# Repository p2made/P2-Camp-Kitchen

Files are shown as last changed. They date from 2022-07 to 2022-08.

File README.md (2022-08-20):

# P2 Camp Kitchen

A tow bar mounted camping kitchen.

--

This work is licensed under the [GNU General Public License v2.0](LICENSE).

--

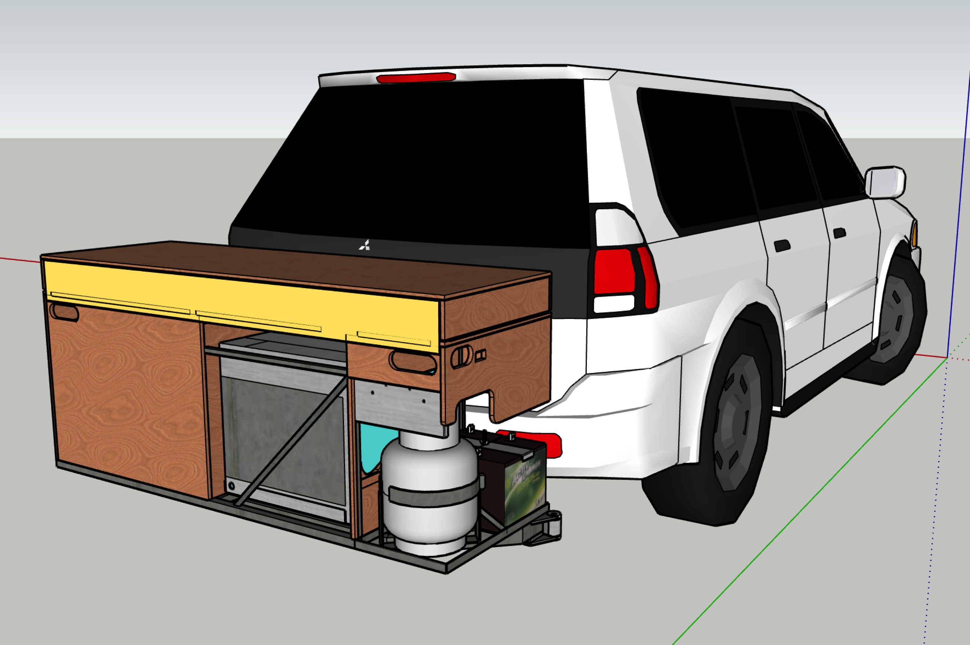
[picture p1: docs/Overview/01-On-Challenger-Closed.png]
01 On Challenger Closed

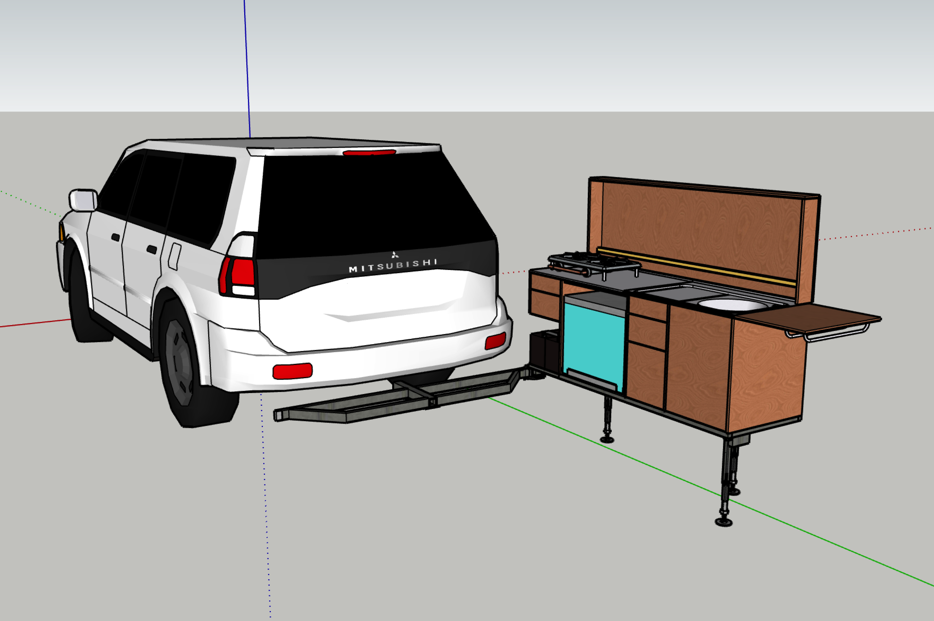
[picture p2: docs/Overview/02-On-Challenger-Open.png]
02 On Challenger Open


--
## Index

1. [Overview](#overview)
2. [Notes](#notes)
3. [Abbreviations](#abbreviations)

## Docs

1. [Detail](docs/Detail.md) ([PDF](docs/Detail.pdf))
2. [Frame](docs/Frame.md) ([PDF](docs/Frame.pdf))
3. [Plywood](docs/Plywood.md) ([PDF](docs/Plywood.pdf))
4. [Undercarriage](docs/Undercarriage.md) ([PDF](docs/Undercarriage.pdf))
5. [Components](docs/Components.md) ([PDF](docs/Components.pdf))
6. Electrical, Electronic, & Lighting
<!--6. [Electrical, Electronic, & Lighting](docs/Electrical.md) ([PDF](docs/Electrical.pdf))-->
7. [Sheet Metal](docs/Sheet-Metal.md) ([PDF](docs/Sheet-Metal.pdf))
8. Assemblies
<!--8. [Assemblies](docs/Assemblies.md) ([PDF](docs/Assemblies.pdf))-->

[PDF of this document](README.pdf).

##  Overview

03 Front
04 Back
05 Open Left
06 Open Right
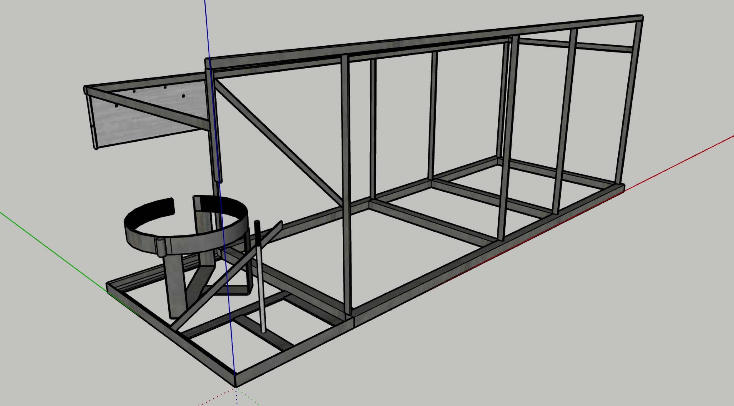
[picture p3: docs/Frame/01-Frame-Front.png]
01 Frame Front

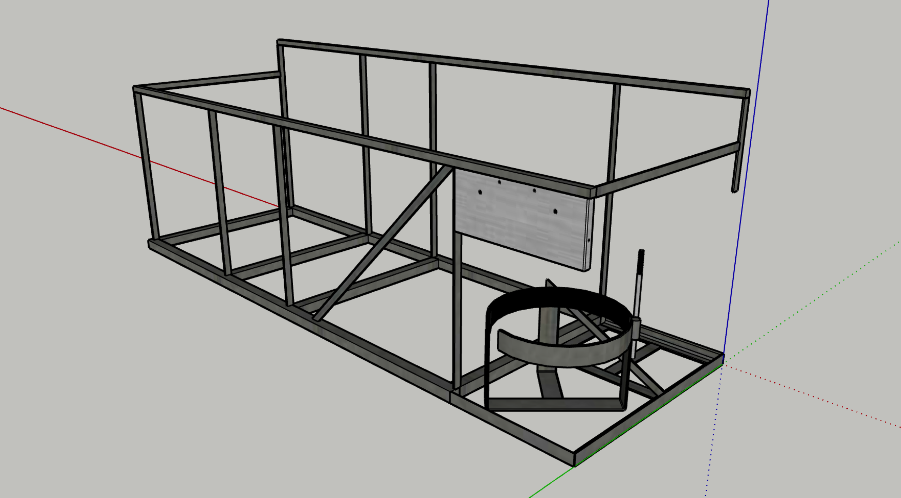
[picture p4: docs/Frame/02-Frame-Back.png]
02 Frame Back


##  *Notes*

“Front”, “Back”, “Left”, & “Right” are from the viewpoint of facing the 1600 mm side that is the kitchen front when deployed & to the front when stowed. That makes “left” & “right” opposite to car driver’s seat viewpoint.

##  Abbreviations

To be concise a number of arbitrary abbreviations are used throughout these docs. These are all defined here.

<table>
	<tr valign="top">
		<td width="33%">
			<dl>
				<dt>LH</dt><dd>Left Hand</dd>
				<dt>LF</dt><dd>Left hand Front</dd>
				<dt>LB</dt><dd>Left hand Back</dd>
			</dl>
		</td>
		<td width="33%">
			<dl>
				<dt>RH</dt><dd>Right Hand</dd>
				<dt>RF</dt><dd>Right hand Front</dd>
				<dt>RB</dt><dd>Right hand Back</dd>
			</dl>
		</td>
		<td width="33%">
			<dl>
				<dt>D</dt><dd>Drawer</dd>
				<dt>Dn</dt><dd>Drawer <i>n</i> = 1 to 5</dd>
			</dl>
		</td>
	</tr>
</table>

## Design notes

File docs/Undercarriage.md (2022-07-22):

# Undercarriage

1. [Overview](#01)
2. [Base](#02)
3. [Under Frame](#03)
4. [Energy Subframe](#04)
5. [Assembly](#05)

--

Made principally from…

* 25x50 mm RHS
* 50x50 mm RHS

**NOTE:** While researching I have seen "receiver" used for the towbar mounting socket on the vehicle, & "shank tube" for the part that plugs into the receiver. I use the same terms here.

##  Overview

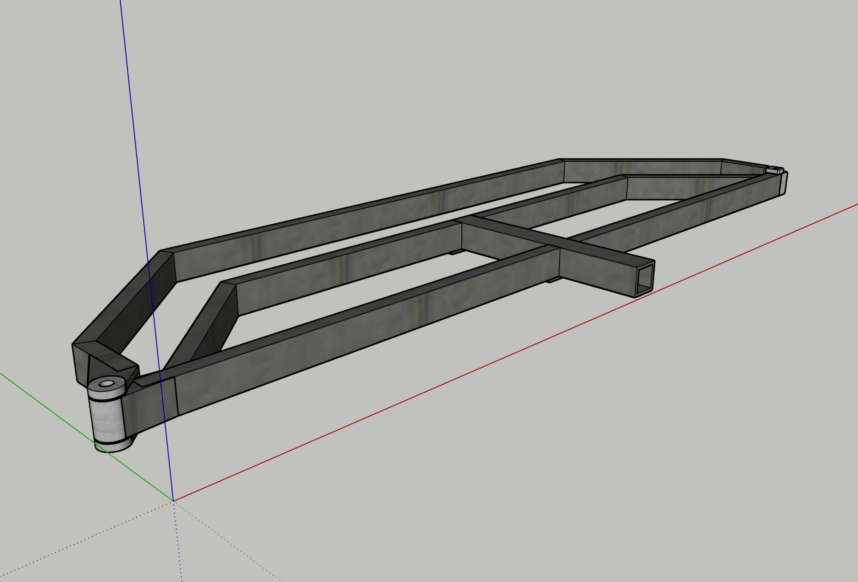
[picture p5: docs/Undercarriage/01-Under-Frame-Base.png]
01 Under Frame & Base


The design intention is for the bottom front rail of the box frame to be positioned directly above the front cross member of the base. 

##  Base

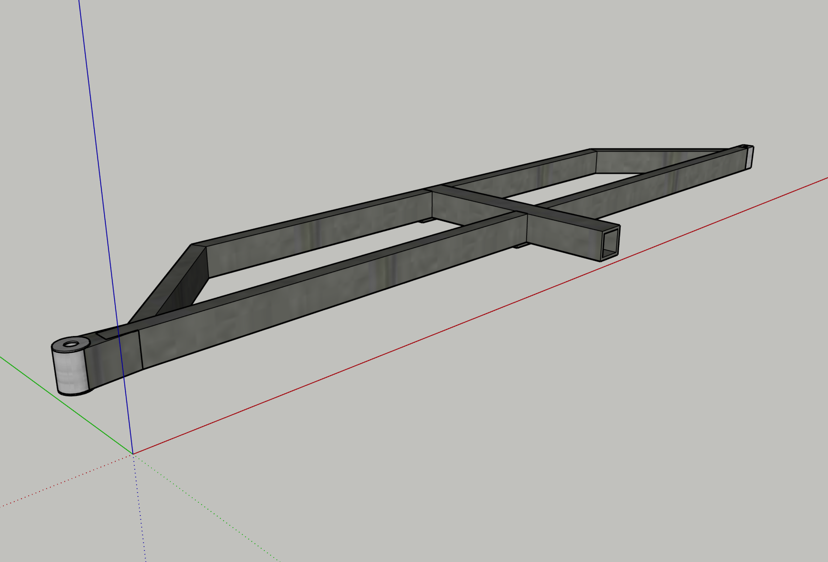
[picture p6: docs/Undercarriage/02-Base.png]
02 Base


The base mounts to the vehicle with the central tube serving as shank tube & going into the receiver on the vehicle.

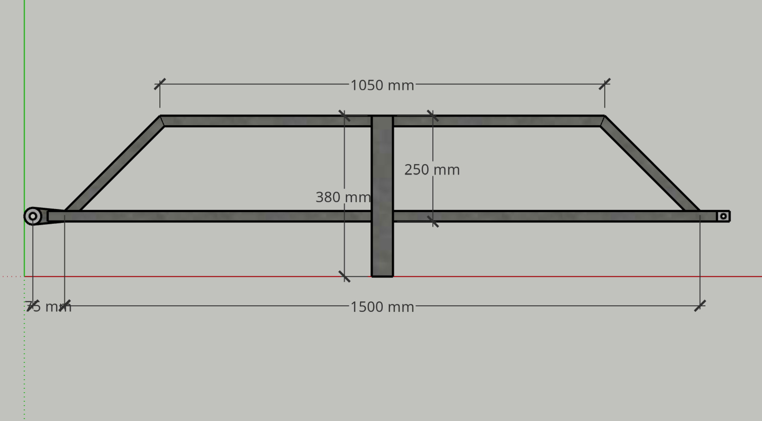
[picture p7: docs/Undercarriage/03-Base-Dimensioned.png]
03 Base Dimensioned


* The length of the shank tube is drawn to go the full 130 mm depth of the receiver on my vehicle. Making it a few mm shorter may be desirable.
* Hole to suit 5/8" hitch pin needs to be positioned to suit the receiver on my vehicle & is not drawn.
* Cross pieces to facilitate attachment of the step (see [Components](Components.md)) need to be add as the engineer sees fit.

The 1050 mm dimension above puts the angled members at 45°, however that only needs to be wide enough to fit the step underneath. The alternate drawing below makes that 600 mm (width of the step rounded up to 100 mm).

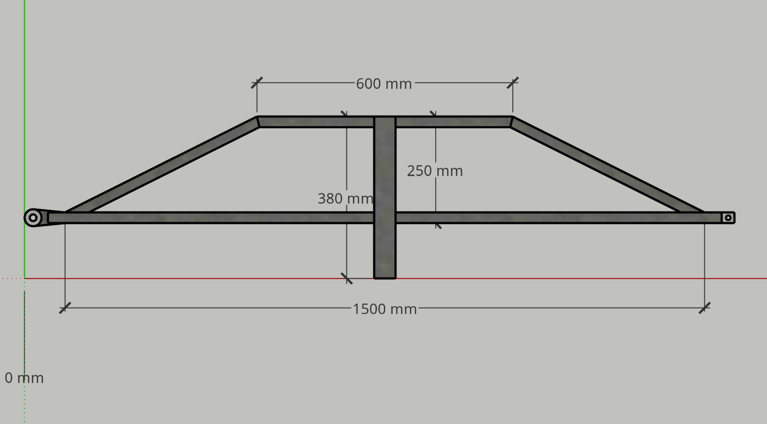
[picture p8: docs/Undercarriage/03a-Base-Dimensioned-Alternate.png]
03a Base Dimensioned Alternate


##  Under Frame

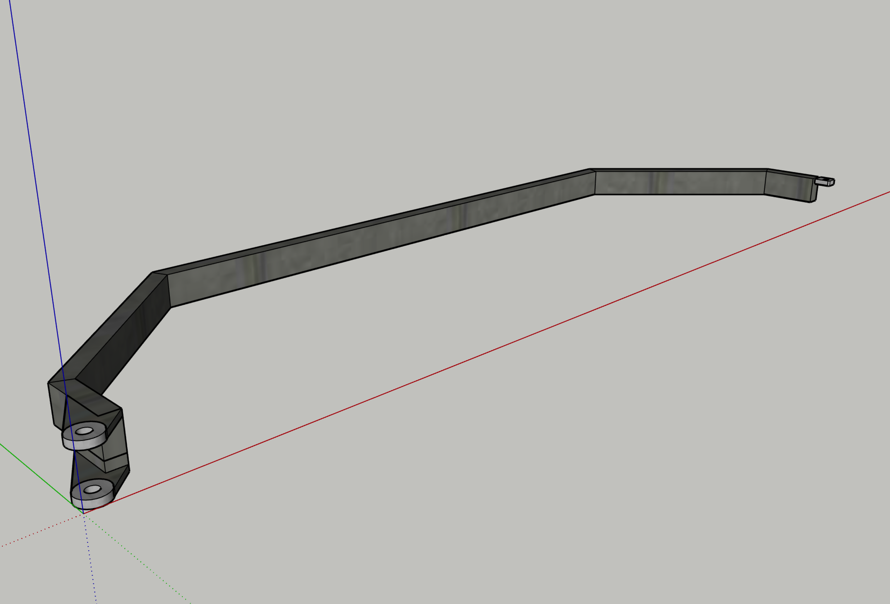
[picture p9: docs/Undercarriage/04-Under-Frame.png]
04 Under Frame


The Under Frame supports the kitchen box & provides the mounting points to the base.

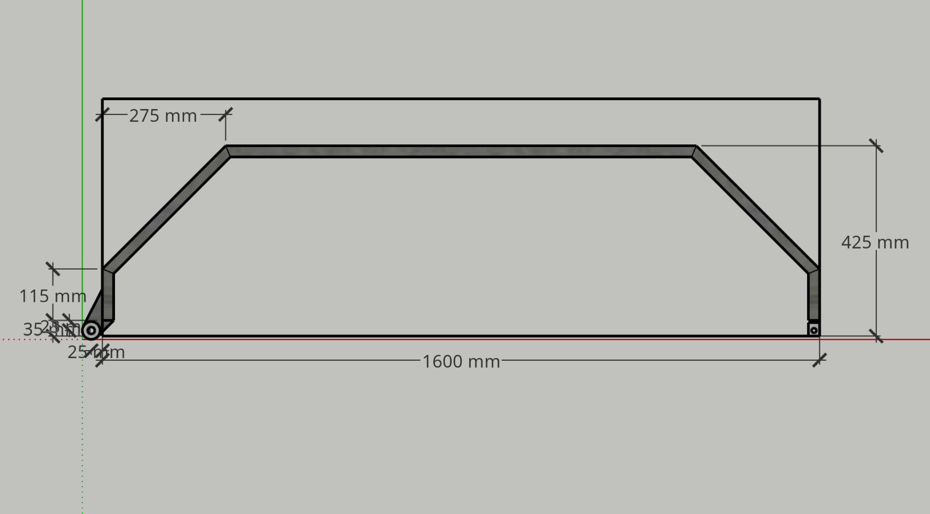
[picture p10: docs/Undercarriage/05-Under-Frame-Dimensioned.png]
05 Under Frame Dimensioned

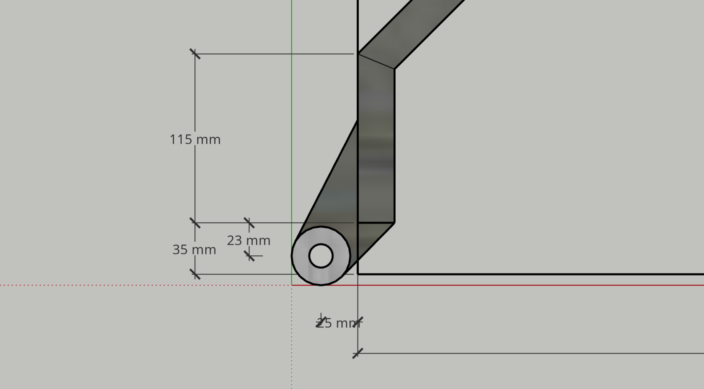
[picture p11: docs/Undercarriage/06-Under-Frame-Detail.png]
06 Under Frame Detail


<!--
## Pivot

[![07 Base Pivot](Undercarriage/07-Base-Pivot.png)](Undercarriage/07-Base-Pivot.pdf "07 Base Pivot")
[![08 Pivot Top](Undercarriage/08-Pivot-Top.png)](Undercarriage/08-Pivot-Top.pdf "08 Pivot Top")
[![09 Pivot Bottom](Undercarriage/09-Pivot-Bottom.png)](Undercarriage/09-Pivot-Bottom.pdf "09 Pivot Bottom")
[![10 Pivot Spacer](Undercarriage/10-Pivot-Spacer.png)](Undercarriage/10-Pivot-Spacer.pdf "10 Pivot Spacer")
-->

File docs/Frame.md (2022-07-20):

# Frame

1. [Overview](#01)
2. [Bottom Frame](#02)
3. [Front & Back Frames](#03)
4. [Energy Subframe](#04)
5. [Assembly](#05)

--

Made principally from…

* 25x25 mm RHS
* 15x15 mm RHS
* 16x3 mm flat steel
* 25x3 mm flat steel

##  Overview

01 Frame Front
02 Frame Back

##  Bottom Frame

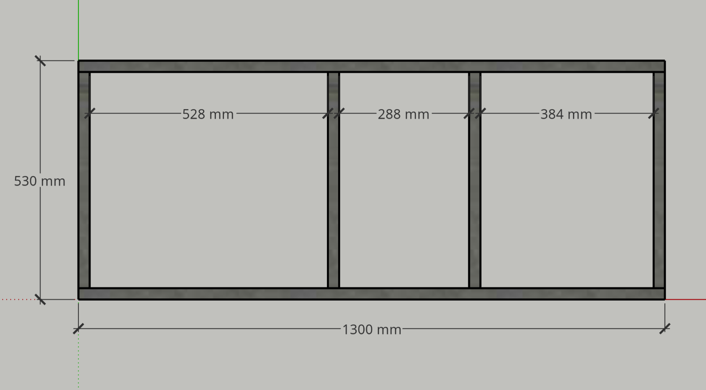
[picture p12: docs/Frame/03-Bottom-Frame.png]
03 Bottom Frame


* All 25x25 RHS.
* Bottom rails, 1300 mm long, spaced 480 mm apart.
* Cross members, 480 mm long, positioned as shown.

##  Front & Back Frames

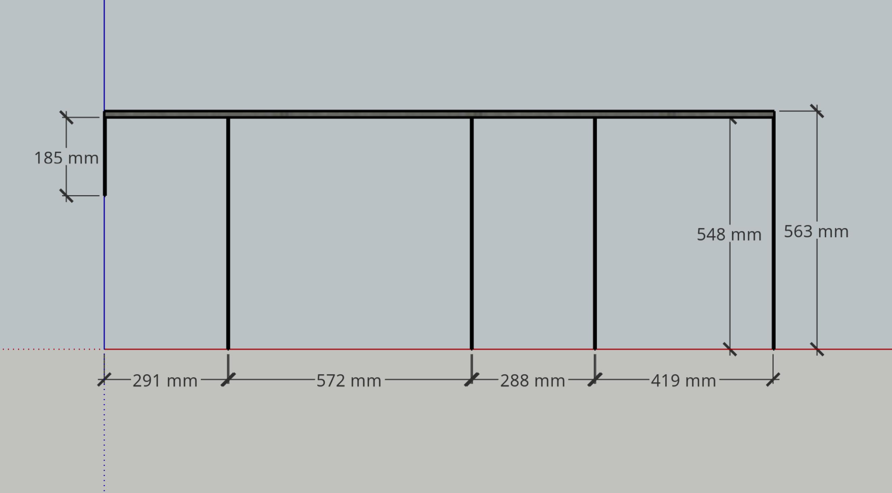
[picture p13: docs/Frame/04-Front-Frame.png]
04 Front Frame

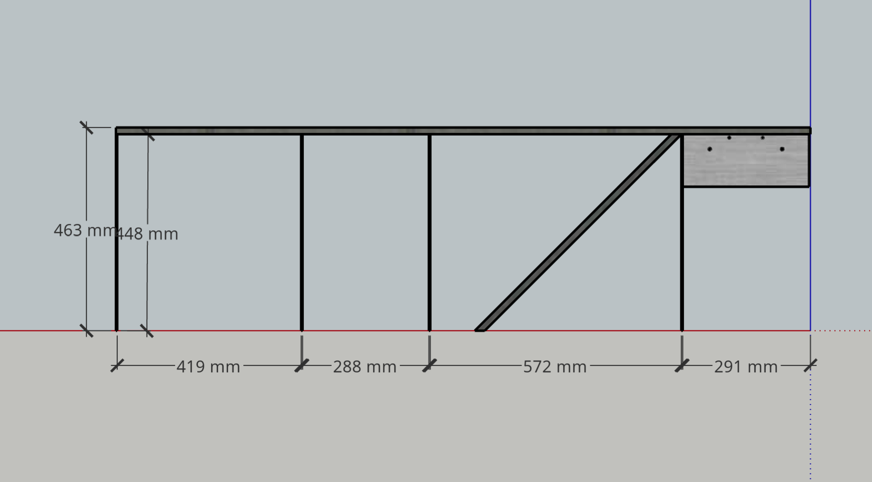
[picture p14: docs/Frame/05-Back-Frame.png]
05 Back Frame


The front & back frames are mirror images of each other with some differences.

* Top members of 15x15 RHS, 1582 long.
* Assembled flush to the outside face.
* Have vertical members of 16x3 flat attached as shown.

### Front Frame

* Vertical members are 548 mm for an overall height of 563 mm.
* Has an additional vertical member, 185 mm long, drawn attached *under* the LH end.
* That additional vertical member could be attached over the end by making appropriate adjustments to dimensions. It has been drawn attached under to minimise the number of items in a cutting list.

### Back Frame

* Vertical members are 448 mm for an overall height of 463 mm.
* Has a number plate mount attached as shown.
* Has a 45° diagonal brace as shown.

### Number Plate Mount

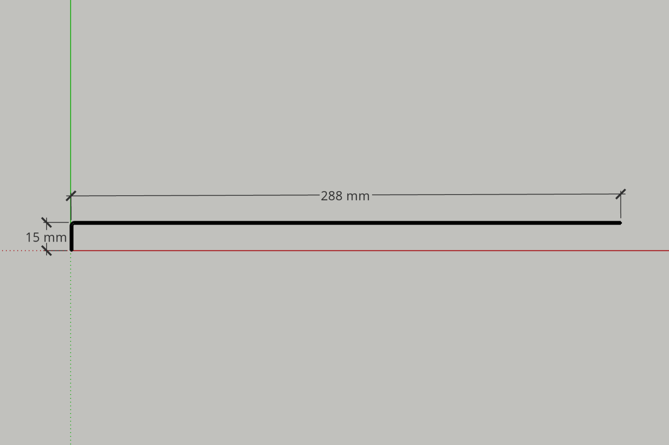
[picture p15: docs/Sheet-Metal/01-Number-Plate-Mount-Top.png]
01 Number Plate Mount Top

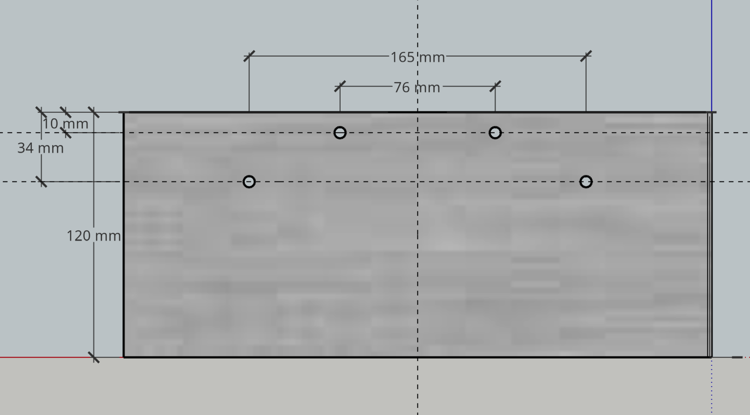
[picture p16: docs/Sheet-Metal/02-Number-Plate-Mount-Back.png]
02 Number Plate Mount Back


##  Energy Subframe

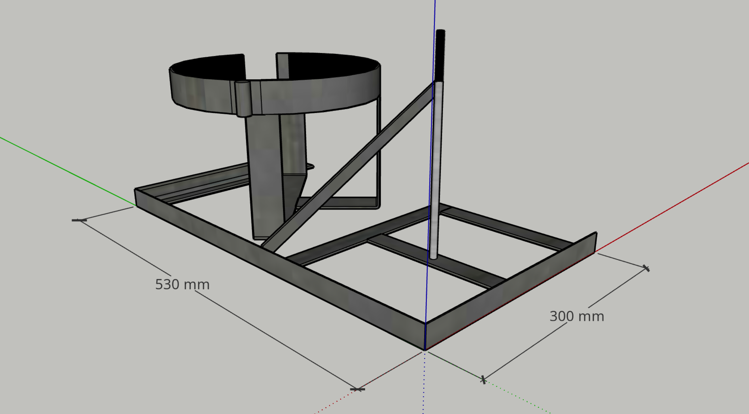
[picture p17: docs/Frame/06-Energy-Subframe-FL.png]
06 Energy Subframe FL

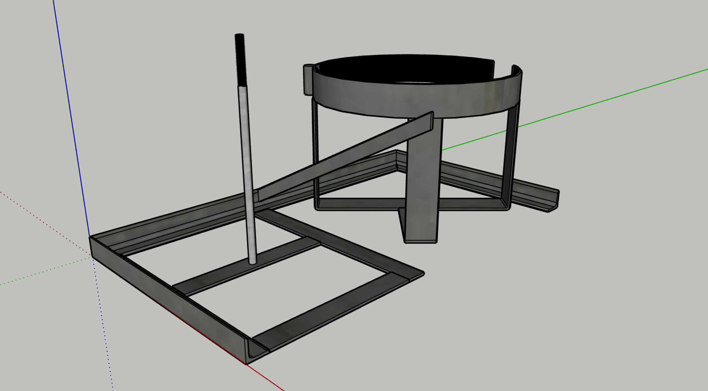
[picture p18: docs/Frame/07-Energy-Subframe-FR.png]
07 Energy Subframe FR


A subframe to support gas bottle & batteries.

Three sides of a rectangle 530 mm (one side) x 300 mm (both sides), made of 25x25 angle, as shown.

Plan views of the energy subframe with horizontal & vertical batteries…

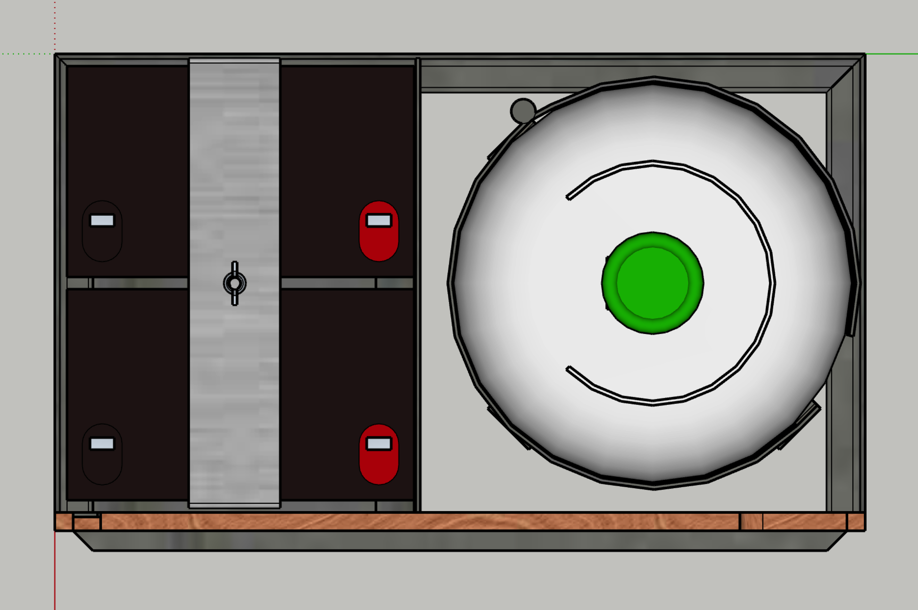
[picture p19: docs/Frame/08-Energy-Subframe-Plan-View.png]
08 Energy Subframe Plan View

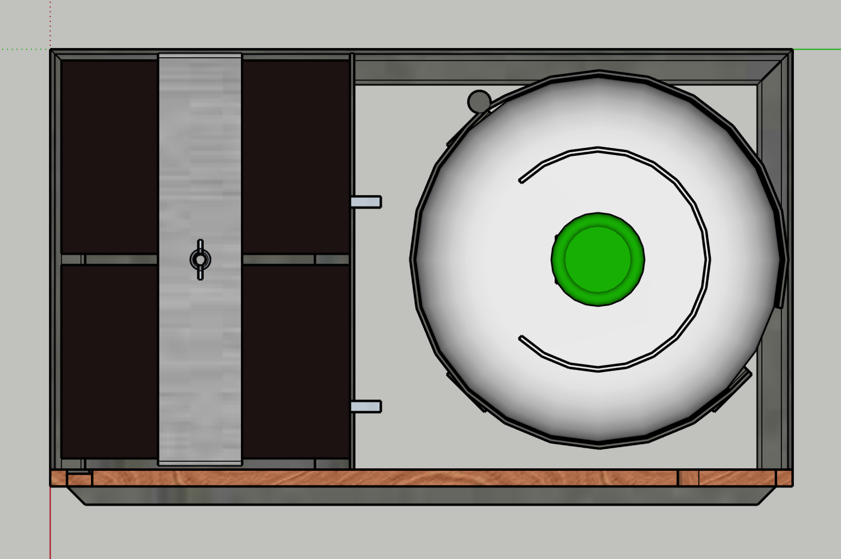
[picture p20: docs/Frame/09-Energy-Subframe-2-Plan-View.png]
09 Energy Subframe 2 Plan View


### Gas Bottle Holder

* An [eBay purchase](https://www.ebay.com.au/itm/254621457008).
* To be modified to sit at approximately 45 degrees within the  Energy Subframe to permit opening without interference.
* Drawings show it positioned 3 mm inside the imagary back face, & centred left to right.

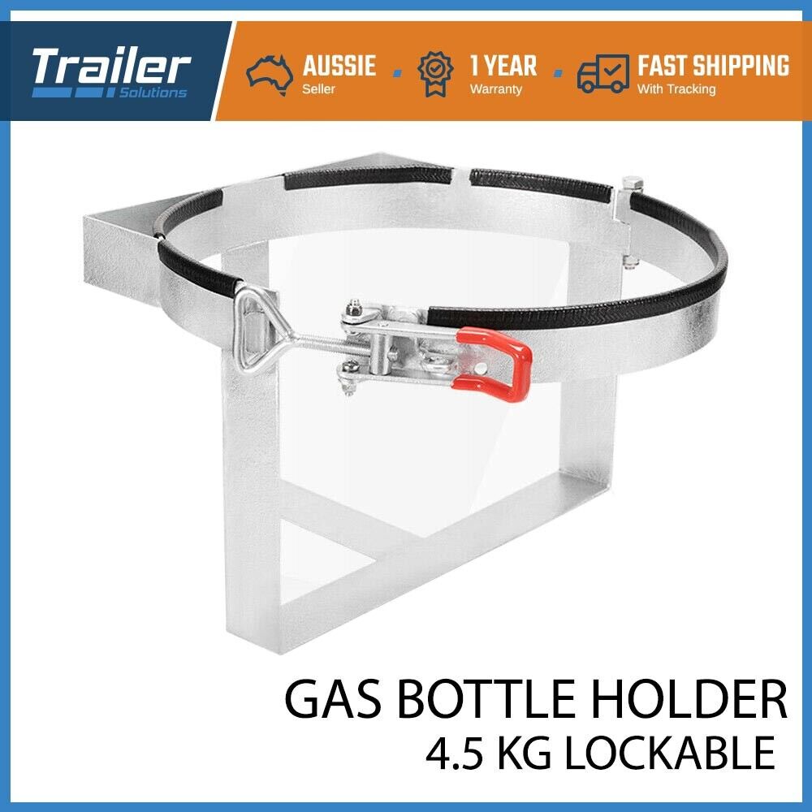
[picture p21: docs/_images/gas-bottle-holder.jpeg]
gas-bottle-holder


### Battery Holder

The battery holder as shown is for illustration only. It may be however the engineer chooses to achieve…

* Batteries positioned as close as practical to the inside face of the front angle.
* The first battery is positioned as close as practical to the inside face of the LH angle.
* The spaces between the batteries, & between the imaginary RH surface of the subframe, are approximately equal.
* The batteries are retained & kept in position by a simple, yet secure, means.

The diagonal brace shown is a possible way to maintain battery position in the back direction while adding support to the structure.

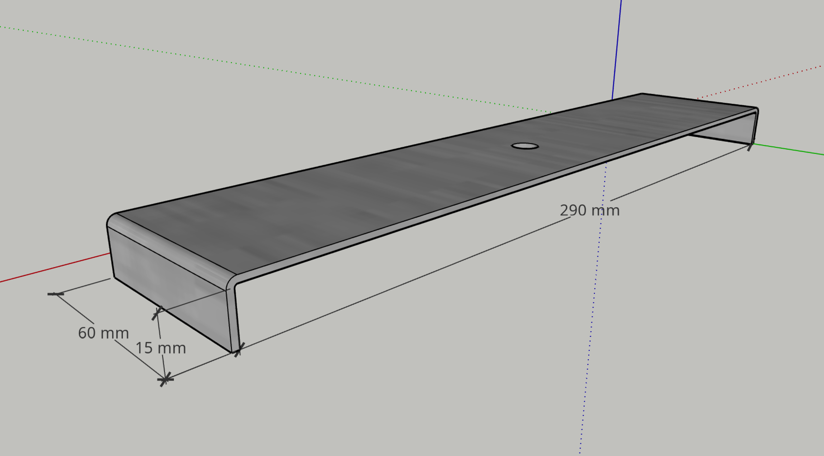
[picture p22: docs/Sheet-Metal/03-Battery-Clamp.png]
03 Battery Clamp


##  Assembly

The front & back frames are attached to the bottom frame…

* Flush to the LH end.
* 9 mm inboard of the RH end.
* 12 mm inboard of their respective faces.

There are 2 x cross members of 16 x 3 mm flat, & one cross member of 25 x 3 mm flat.

The 16 mm cross members are flush in the end planes of the top rails, running horizontally from the inside face of the back top rail to the adjacent front vertical.

The 25 mm cross member runs horizontally between the LH pair of verticals, at a height for attachment to the band of the gas bottle holder (with a spacer if necessary). The actual height must be advised for appliction to plywood cutting.

The energy rack is attached to the LH end of the bottom frame.

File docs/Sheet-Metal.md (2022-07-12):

# Sheet Metal

1. [Number Plate Mount](#01)
2. [Battery Clamp](#02)
3. [Fridge Tray Rails](#03)
4. [Stainless Steel Top](#04)
5. [Splash Back Cover](#05)

--

##  Number Plate Mount

* To be attached to the back frame.
* Drawn as 1 mm sheet metal.

01 Number Plate Mount Top
02 Number Plate Mount Back

##  Battery Clamp

* Drawn as 2 mm sheet metal.

03 Battery Clamp

##  Fridge Tray Rails

* Drawn as 2 mm sheet metal.

Side rails.

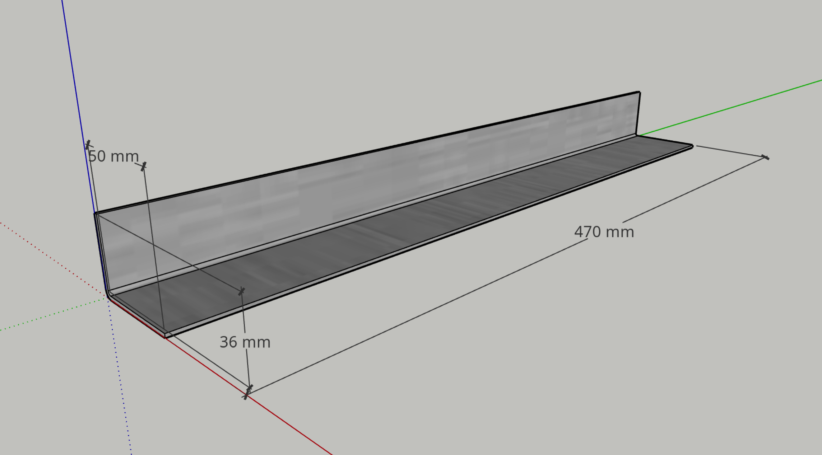
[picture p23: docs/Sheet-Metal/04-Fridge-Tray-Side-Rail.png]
04 Fridge Tray Side Rail


Front rail.

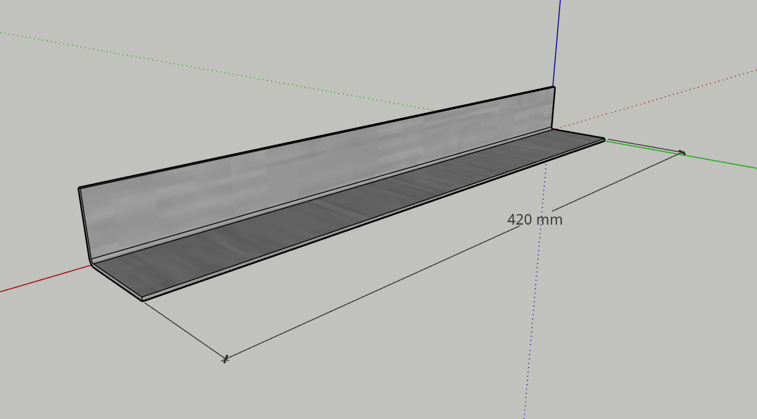
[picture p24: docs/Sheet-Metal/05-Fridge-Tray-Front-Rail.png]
05 Fridge Tray Front Rail


Back rail (same as front with cutout for access to pilot light hole).

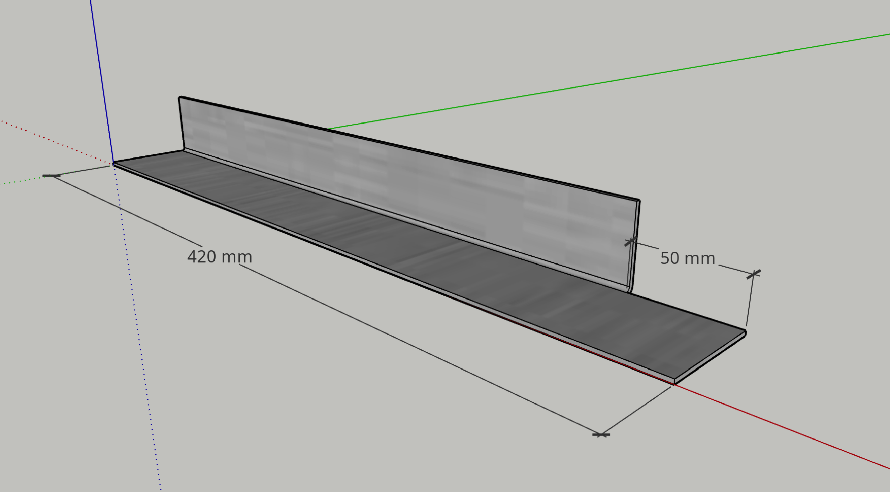
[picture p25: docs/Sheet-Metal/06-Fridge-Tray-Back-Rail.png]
06 Fridge Tray Back Rail


##  Stainless Steel Top

* To complement the sink in making a full stainless steel surface for the benchtop.
* Should have holes (not yet drawn) for stove attachment.
* Drawn as 1 mm, but should match the thickness of sink steel.

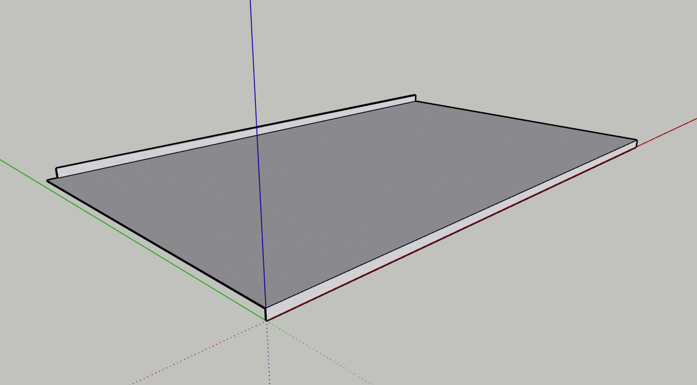
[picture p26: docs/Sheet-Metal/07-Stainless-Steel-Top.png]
07 Stainless Steel Top


##  Splash Back Cover

* A cover for the top & rear of splash back.
* Has a return section to enclose pipes & wiring above fridge.
* Dimensions shown are *inside* the folds.
* Drawn as 1 mm, but should be less.

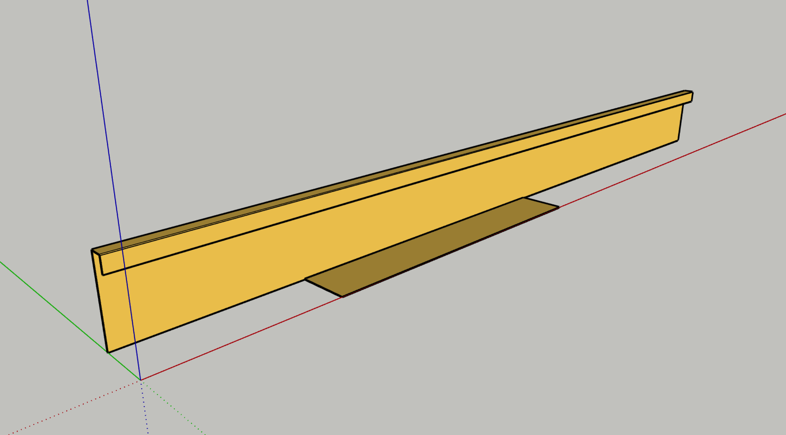
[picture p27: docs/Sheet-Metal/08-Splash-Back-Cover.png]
08 Splash Back Cover

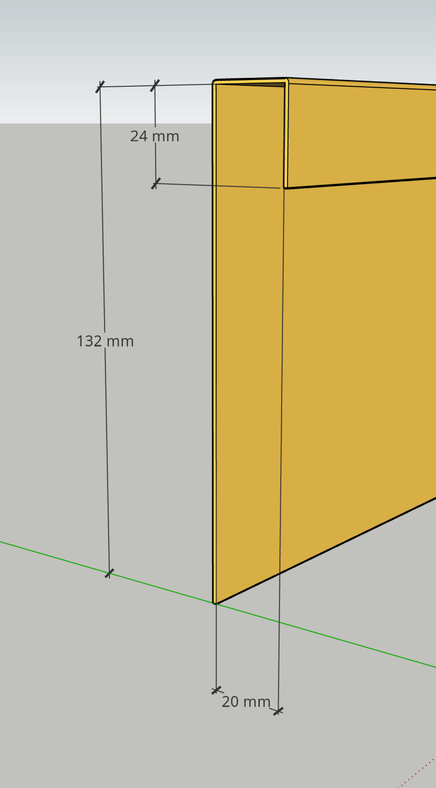
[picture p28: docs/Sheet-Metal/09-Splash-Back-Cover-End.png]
09 Splash Back Cover End


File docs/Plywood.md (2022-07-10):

# Plywood

1. [Cross Panels](#01)
2. [Back Panels](#02)
3. [Benchtop](#03)
4. [Drawers](#04)
5. [Cupboard](#05)
6. [Splash Back](#06)
7. [Lid](#07)
8. [End Shelf](#08)

--

Pieces cut from 12 mm marine ply.

Where there is no drawing, there is either...

* No additional detail, or
* Additional details haven't yet been drawn.

##  Cross Panels

* Five cross members, LH, RH, & 1 to 3 numbered LH to RH.
* Routing is 3mm deep & drawn with 2 mm with clearance.

### End Panel LH

* 530 x 250 mm.
* Hole for water hoses.
* Hole (drawn) or recess for clearance light.
* Cutout for gas bottle access.

01 End Panel LH

### End Panel RH

* 530 x 563 mm.
* Hole (drawn) or recess for clearance light.

02 End Panel RH

### Cross Panel 1

* 530 x 563 mm.
* Hole for gas hose movement.
* Cutouts for frame top rails.
* Cutout for pipe & wiring.
* Cutout for LH back panel.

03 Cross Panel 1

### Cross Panel 2

* 518 x 563 mm.
* Cutouts for frame top rails.
* Cutout for pipe & wiring.

04 Cross Panel 2

### Cross Panel 3

* Mirror of cross panel 2.

05 Cross Panel 3

##  Back Panels

Two back panels, both having holes for mounting taillights.

* Back Panel LH: 300 x 115 mm.
* Back Panel RH: 722 x 563 mm.

06 Back Panel LH
07 Back Panel RH

##  Benchtop

* 1600 x 530 mm.
* Hole for sink.
* Cutout for wiring to splash back.

08 Benchtop

##  Drawers

Provision for hardware not yet shown.

Five drawers with front panels…

* Drawer fronts 1 & 3, 284 x 96 mm, for a nominal depth of 100 mm.
* Drawer fronts 2 & 4, 284 x 146 mm, for a nominal depth of 150 mm.
* Drawer front 5, 284 x 305 mm, for a nominal depth of 309 mm (with 4 mm clearance below).

Drawers 1 & 2 are special purpose drawers…

* Drawer 1, 350 mm long with the bottom set high for an effective depth of 50 mm.
* Drawer 2, 250 mm long with a rail across the top back instead of a back panel, so that there is a large opening for wiring.

The rest of the drawers are entirely standard, & as long as possible. Some internal division in drawers 3 & 4 may be desirable.

##  Cupboard

Door 406 x 555 mm. Provision for hardware not yet shown.

Floor 384 x 480 mm. Requires an opening at LB corner for passage of sink waste hose (drawn as 70 mm radius quarter circle).

13 Cupboard Floor

Shelf 410 x 500 mm. Requires hole under centre of sink bowl for passage of sink waste hose (drawn as 70 diameter but smaller would be preferable).

14 Cupboard Shelf

##  Splash Back

* 1570 x 100 mm.
* Holes (not yet drwan) near centre for switchgear.

##  Lid

Provision for hardware not yet shown.

Four sides of a 1600 x 530 x 112 mm box.
Pieces are…

* 1600 x 530 mm for top.
* 1600 x 100 mm for front.
* 2 of 518 x 100 mm for ends.

##  End Shelf

* 400 x 530 mm.
* To attach to RH end when deployed.

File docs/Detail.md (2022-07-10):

# Detail

1. [Front & Back Views](#01)
2. [Left & Right Views With Lid Open](#02)
3. [Closer Views of Lid Closed & Lid Open](#03)
4. [Superimposed Lid Positions](#04)
5. [Stove Detail](#05)
6. [Sink Detail](#06)
7. [Front & Back Views of Energy Subframe](#07)

--

##  Front & Back Views

01 Front
02 Back

##  Left & Right Views With Lid Open

03 Open Left
04 Open Right

##  Closer Views of Lid Closed & Lid Open

05 Lid Closed
06 Lid Open

##  Superimposed Lid Positions

07 Lid Positions

##  Stove Detail

08 Stove Detail

##  Sink Detail

09 Sink Detail

##  Front & Back Views of Energy Subframe

10 Subframe Front
11 Subframe Back




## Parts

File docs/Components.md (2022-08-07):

# Components

1. [Sink](#01)
2. [Stove](#02)
3. [Gas Bottle Holder](#03)
4. [Legs](#04)
5. [Fridge Tray](#05)
6. [Caravan Level](#06)
7. [Caravan Step](#07)
8. [Lid Hinge](#08)

--

##  Sink

Drawing is model of 2nd hand caravan sink. Has a mixer tap fitted.

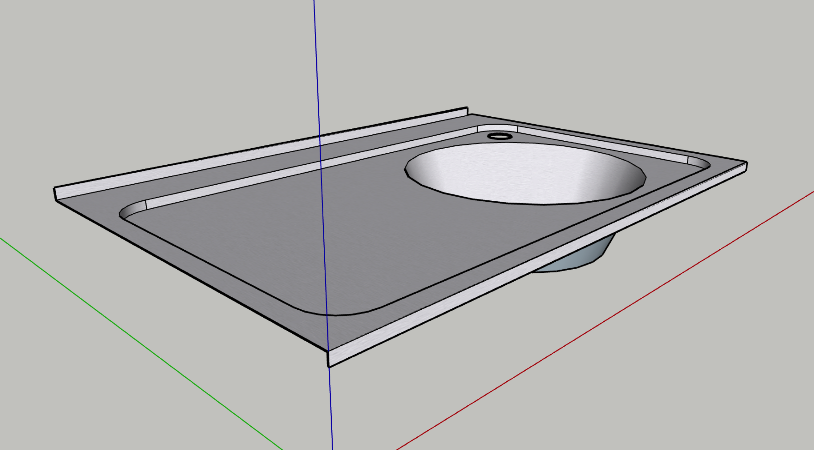
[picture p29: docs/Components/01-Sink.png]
01 Sink


##  Stove

The stove has cast iron legs attached at the corners with bolts. By replacing the original legs with spacers (standoffs, angle, 15x15 RHS), & using longer bolts, the stove can be solidly attached to the benchtop.

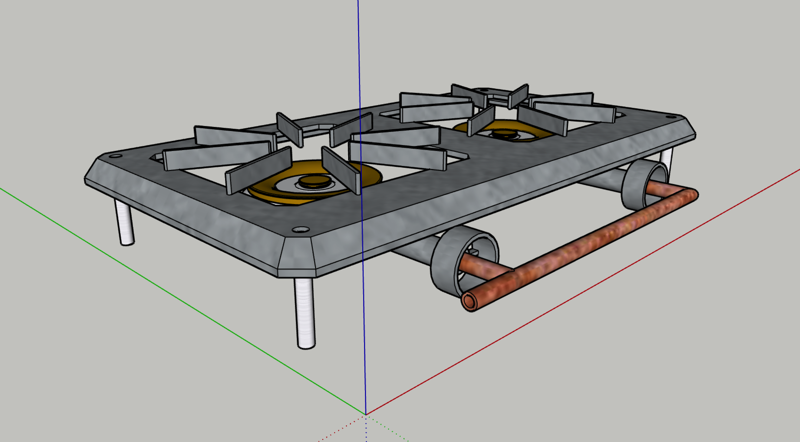
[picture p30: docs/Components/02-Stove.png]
02 Stove


##  Gas Bottle Holder

* [eBay purchase](https://www.ebay.com.au/itm/254621457008)
* To be modified to sit at approximately 45 degrees within the energy subframe.

gas-bottle-holder

##  Legs

* The box should have 2 or 3 adjustable legs to support it in a level position in camp.
* The legs could either be permanently attached on pivots & swing down at camp setup, or be inserted into sockets at camp setup.
* Having a jockey wheel on one leg may be useful to provide support during camp setup.

Two possible versions are drawn…

Version 1, with screw adjustment only.

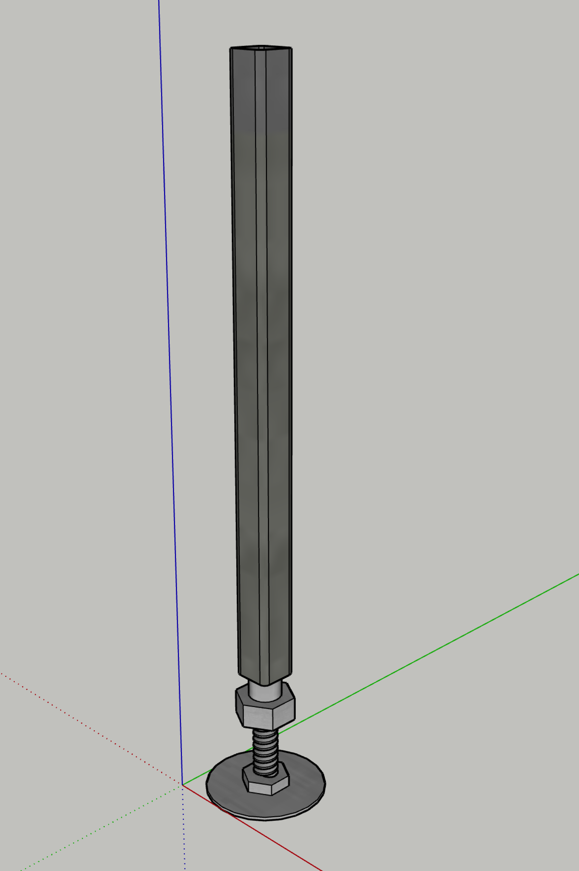
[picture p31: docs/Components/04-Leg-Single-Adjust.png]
04 Leg Single Adjust


Version 2, with slide & screw adjustment.

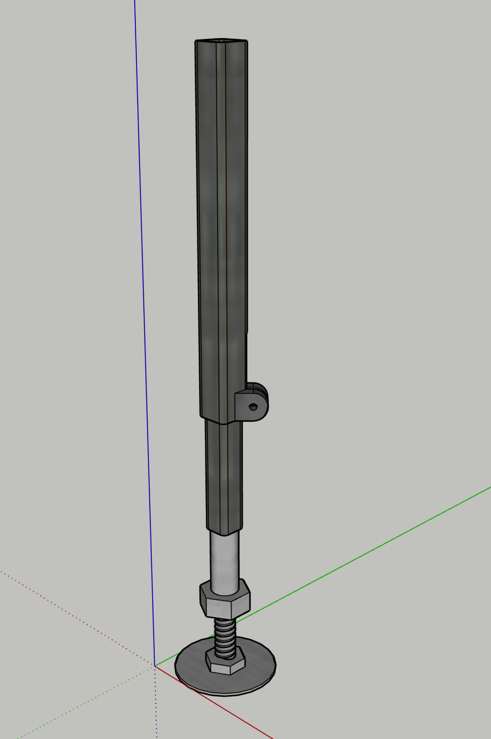
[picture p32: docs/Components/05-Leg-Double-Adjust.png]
05 Leg Double Adjust


Version 3, with hook mount & screw adjustment.

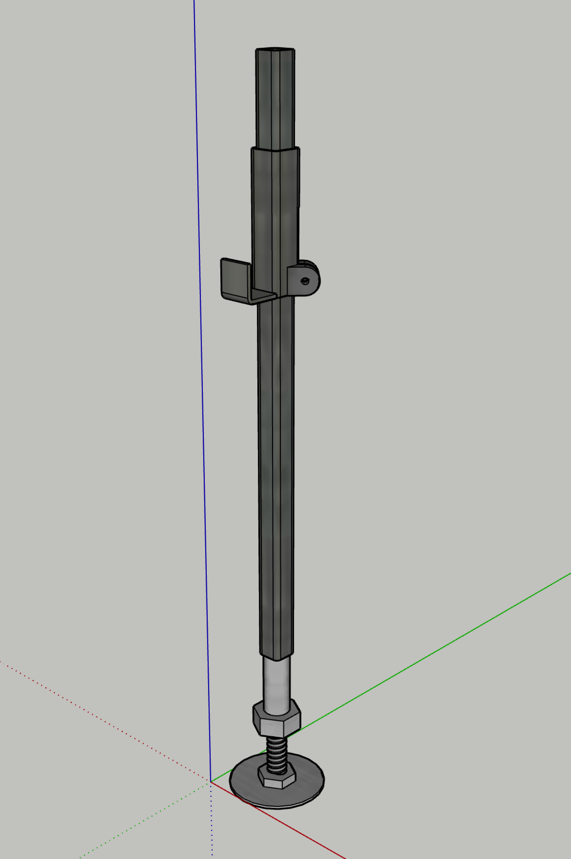
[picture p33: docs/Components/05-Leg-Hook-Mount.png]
05 Leg Hook Mount


##  Fridge Tray

* A rudimentay 'tray' to support the fridge between drawer rails.
* Vertical portions of the sides must be deep enough for attachment of drawer rails.
* The pilot light hole at the bottom RB corner of the fridge must remain unobstructed.
* The drawing uses 4 pieces of angle as described in the Sheet Metal file.

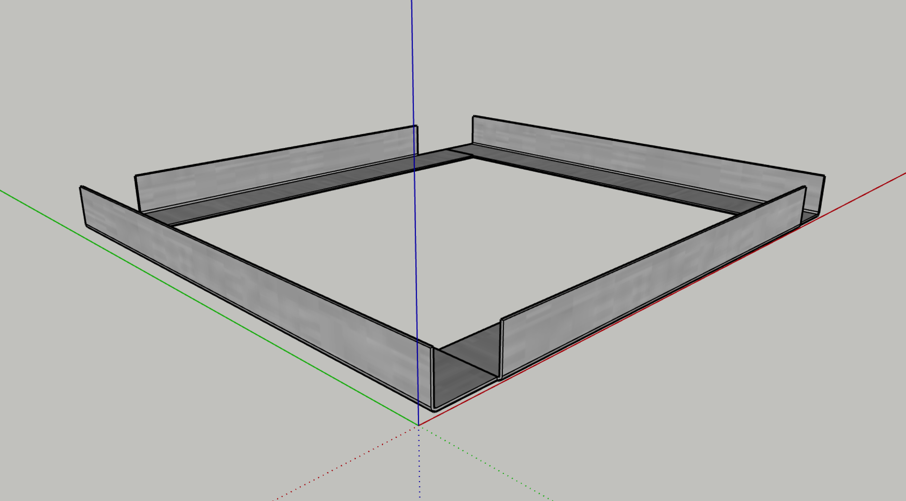
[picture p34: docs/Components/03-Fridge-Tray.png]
03 Fridge Tray


##  Caravan Level

* [eBay purchase](https://www.ebay.com.au/itm/125243519326)
* To be mounted on benchtop as an aid to levelling at camp setup.

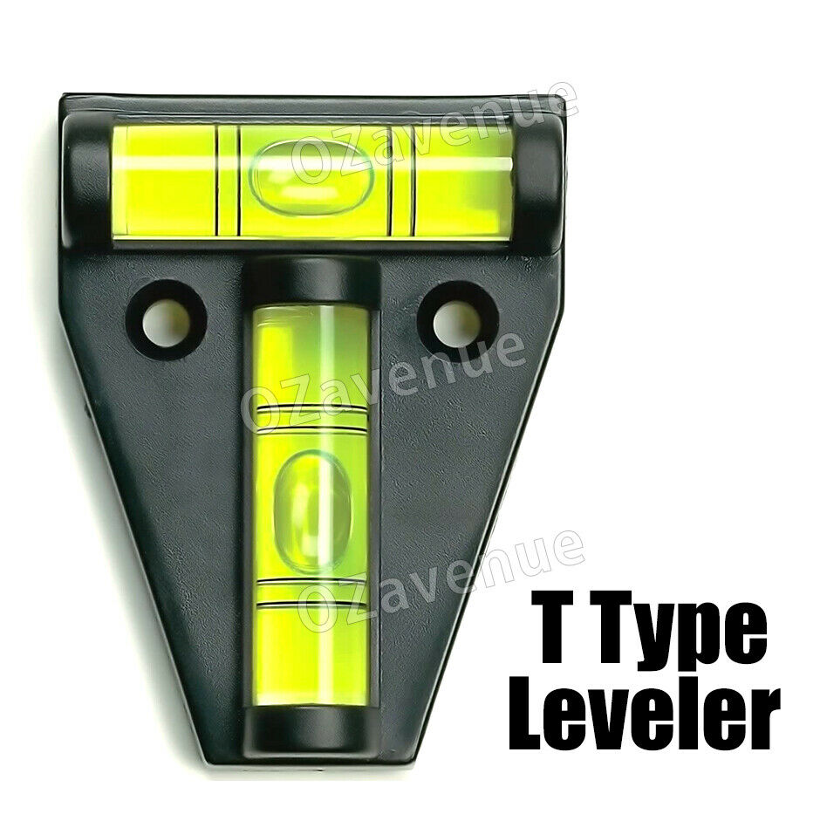
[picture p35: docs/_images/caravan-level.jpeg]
caravan-level


##  Caravan Step

* [eBay purchase](https://www.ebay.com.au/itm/293101007284)
* To be fitted underneath Base.
* Selected item has lighting to be part of safety lighting.

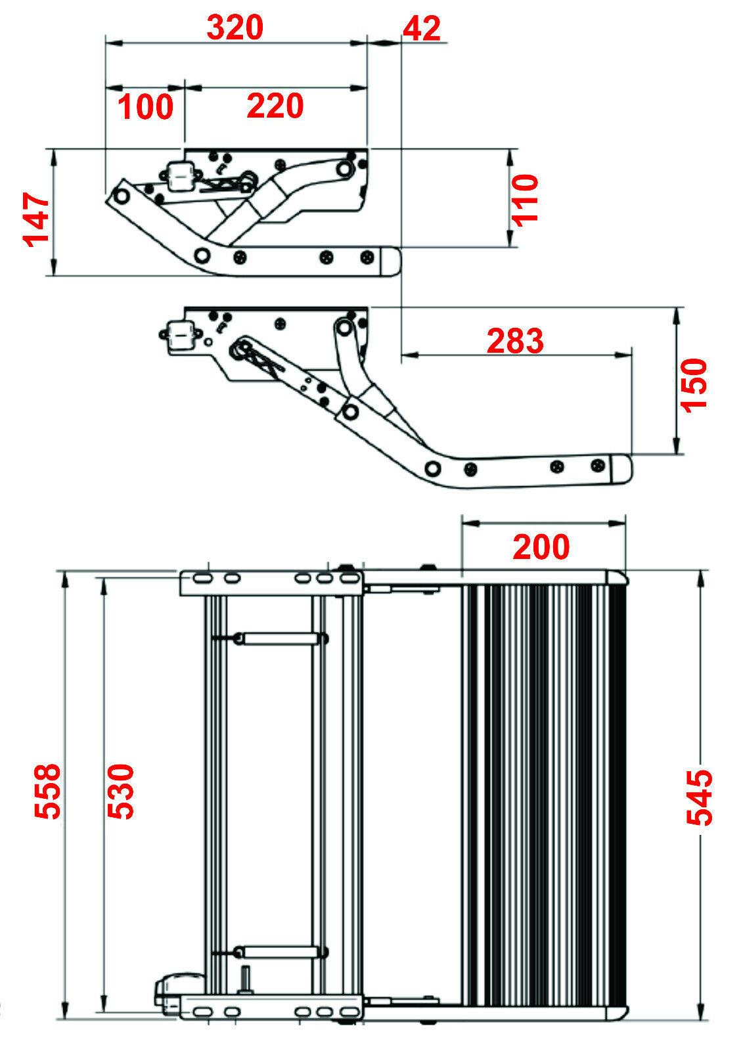
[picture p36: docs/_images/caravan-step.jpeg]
caravan-step


##  Lid Hinge

Custom hinge to provide a right opening action for the lid.

08 Lid Hinge B
07 Lid Hinge A
08 Lid Hinge B

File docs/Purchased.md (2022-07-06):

#Purchased Items

###Caraval level

caravan-level

[eBay purchase](https://www.ebay.com.au/itm/125243519326)

To be mounted on benchtop.

###Gas bottle holder

gas-bottle-holder

[eBay purchase](https://www.ebay.com.au/itm/254621457008)

Will be modified to sit at approximately 45 degrees, & Energy Rack.

###Cravan step

caravan-step

[eBay purchase](https://www.ebay.com.au/itm/293101007284)

Will be fitted underneath Base. Selected item has lighting to be part of safety lighting.









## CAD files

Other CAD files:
skp/Components/Battery.skp
skp/Components/Fridge Tray.skp
skp/Components/Fridge-Tray.skp
skp/Components/Fridge.skp
skp/Components/Leg.skp
skp/Components/Sink.skp
skp/Components/Stove.skp
skp/Frame/Back Frame.skp
skp/Frame/Back-Frame.skp
skp/Frame/Bottom Frame.skp
skp/Frame/Bottom-Frame.skp
skp/Frame/Energy Subframe.skp
skp/Frame/Energy-Subframe.skp
skp/Frame/Frame.skp
skp/Frame/Front Frame.skp
skp/Frame/Front-Frame.skp
skp/Plywood/Back-Panel-LH.skp
skp/Plywood/Back-Panel-RH.skp
skp/Plywood/Benchtop.skp
skp/Plywood/Cross-Panel-1.skp
skp/Plywood/Cross-Panel-2.skp
skp/Plywood/Cross-Panel-3.skp
skp/Plywood/Cupboard-Door.skp
skp/Plywood/Cupboard-Floor.skp
skp/Plywood/Cupboard-Shelf.skp
skp/Plywood/Drawer-Front-1-3.skp
skp/Plywood/Drawer-Front-2-4.skp
skp/Plywood/Drawer-Front-5.skp
skp/Plywood/End-Panel-LH.skp
skp/Plywood/End-Panel-RH.skp
skp/Plywood/End-Shelf.skp
skp/Plywood/Front-Bead.skp
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

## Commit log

2022-07-05 Create 03 Frame.pdf
2022-07-05 Create Number Plate Mount.pdf
2022-07-05 Add SketchUp files to /Frame.
    [Back Frame.skp, Bottom Frame.skp, Energy Rack Plan View.skp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]
2022-07-05 Update 03 Frame.pdf
2022-07-05 Create Battery Clamp.pdf
2022-07-05 Create 03 Frame.md
2022-07-05 Move files to a 'docs' folder.
    [Back Frame.skp, Bottom Frame.skp, Energy Rack Plan View.skp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]
2022-07-06 Remove Frame.md, add _images folder.
2022-07-06 Create Battery Clamp.skp
    [Battery Clamp.skp]
2022-07-06 Update Frame files.
    [Back Frame.skp, Bottom Frame.skp, Energy Rack Plan View.skp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]
2022-07-06 Add Sheet Metal files.
    [Frame.skp, Number Plate Mount.skp]
2022-07-06 Rename Energy Subframe files.
    [Energy Subframe.skp]
2022-07-06 Create Fridge Tray.skp
    [Fridge Tray.skp]
2022-07-06 Sheet metal files.
    [Fridge Tray Side Rail.skp]
2022-07-06 Safe filenames.
    [Back-Frame.skp, Battery-Clamp.skp, Bottom-Frame.skp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]
2022-07-06 Update skp files.
    [Back-Frame.skp, Bottom-Frame.skp, Front-Frame.skp]
2022-07-07 Add Plywood skp files.
    [Back Panel LH.skp, Back Panel RH.skp, Benchtop.skp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]
2022-07-09 Update Frame docs.
2022-07-09 Add new skp files.
    [Back Frame.skp, Back Panel LH.skp, Back Panel RH.skp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]
2022-07-10 Add components.
    [Battery.skp, Fridge.skp, Leg.skp]
2022-07-10 Fix leg filenames.
2022-07-10 Update number plate mount
2022-07-12 Add legs
2022-07-20 Update Frame & Undercarriage md
2022-07-20 Update Under Frame images
2022-07-25 Update frame files
2022-08-06 Add lid hinge.
2022-08-06 Add hinge video.
